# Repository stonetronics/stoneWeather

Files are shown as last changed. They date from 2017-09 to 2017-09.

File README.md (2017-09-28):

# stoneweather
Small IOT Weather station using Wifi Module WeMos D1 Mini, Pressure/Temperature Sensor HP03S, Relative Air Humidity/Temperature Sensor HTU21 LDO AMS1117

Newer version using WeMos D1 Mini, kicking out the ATmega328 to reduce complexity

Hardware Layout drawn in Eagle 8.0
coming soon!

Code for WeMos D1 Mini written in Arduino IDE (esp8266_d1mini_weather_station_v2)
-Measures temperature and air pressure using HP03s (custom .cpp and .h mixed up of "github.com/philippG777/HP03S" and "codebender.cc/sketch:42077#HP03S.ino"
-Measures temperature and relative air humidity using HTU21 (sparkfun Library)
-Displays all Data on a very simple Website to be used by a data collector (see github.com/ringo96/weatherstation)

Old Version using ATmega328 and ESP8266:

Hardware Layout drawn in Eagle 8.0
-Header for ESP8266 and GY21-HTU21 breakout boards mounted SMD
-all components SMD except for LED and XTAL

Code for ESP8266 written in Arduino IDE (esp8266displayUart)
-Reads temperature and air pressure on uart and displays it on a very simple website to be used by a data collector (see github.com/ringo96/weatherstation)

Code for ATMega328 written in Arduino IDE (HP03sUART)
-Measures temperature and air pressure with an HP03S sensor and displays it on uart

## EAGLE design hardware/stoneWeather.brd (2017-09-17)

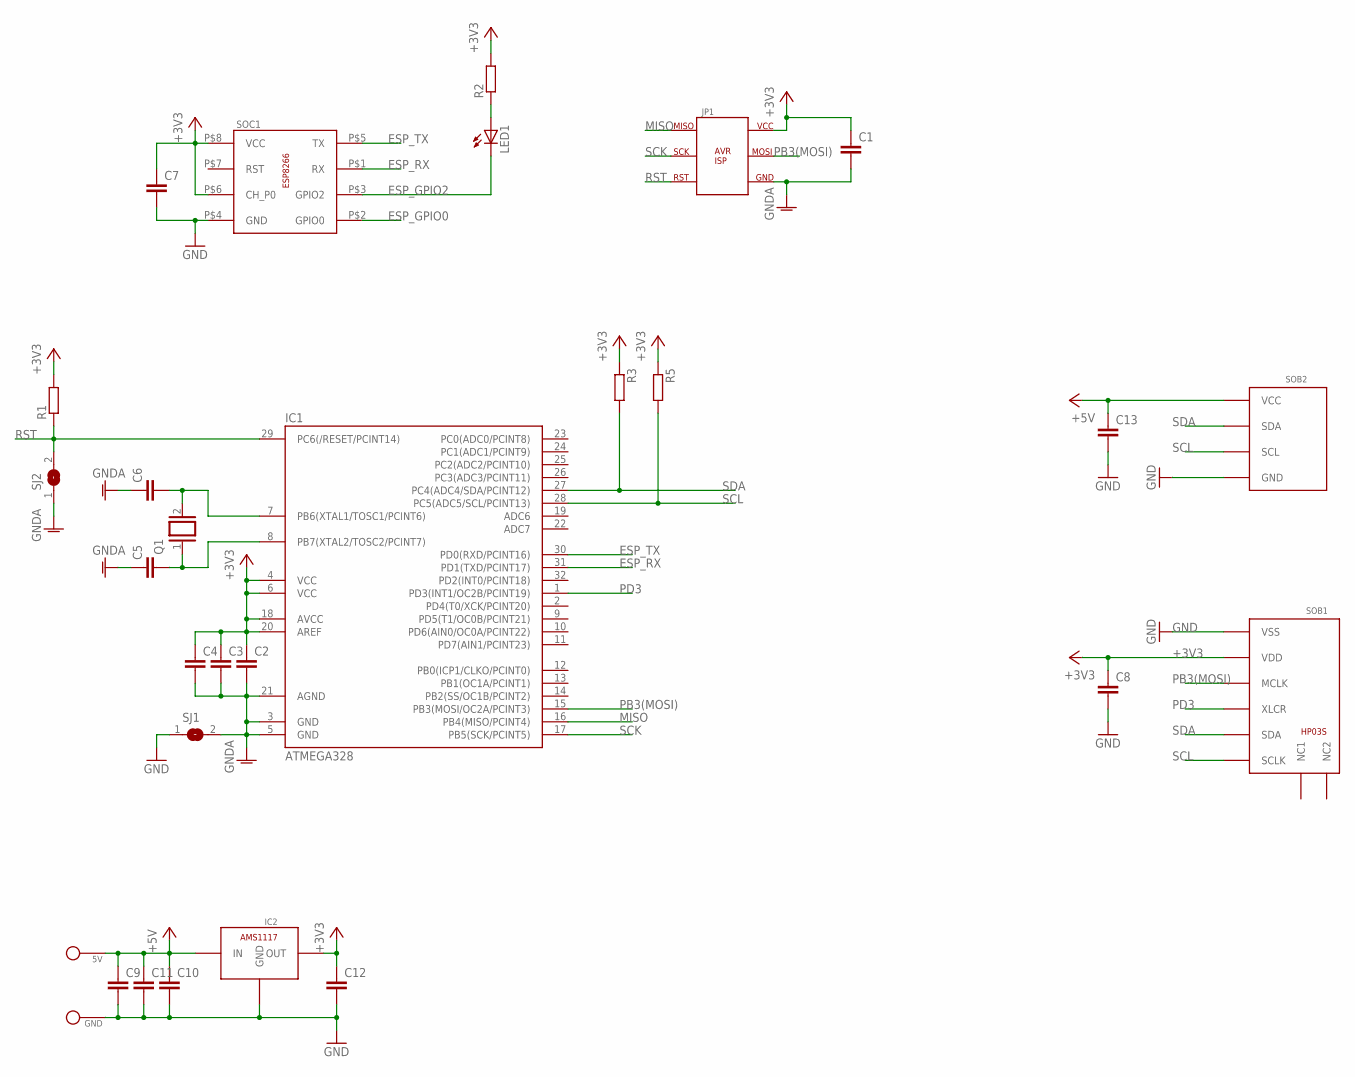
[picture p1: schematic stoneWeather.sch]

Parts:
5V: PAD_254X508
C1, C2, C3, C4, C5, C6, C7, C8, C9, C10, C11, C12, C13: C-EUC0805; C0805
GND: PAD_254X508
IC1: ATMEGA328; TQFP32-08
IC2: AMS1117
JP1: AVR_ISPSINGLESIDED_SMD; PINHEADER_254_2X3_SMD
LED1: LED3MM
Q1: XTAL/S; QS
R1, R2, R3, R5: R-EU_M0805; M0805
SJ1, SJ2: SJ
SOB1: HP03S
SOB2: GY21_HTU21; GY21-HTU21
SOC1: ESP8266PINHEADER_SMD; ESP8266

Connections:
+3V3: C1.1, C2.1, C3.1, C4.1, C7.1, C8.1, C12.1, IC1.4 (VCC), IC1.6 (VCC), IC1.18 (AVCC), IC1.20 (AREF), IC2.OUT, JP1.P$8 (VCC), R1.2, R2.2, R3.1, R5.1, SOB1.VDD, SOC1.P$6 (CH_P0), SOC1.P$8 (VCC)
+5V: 5V.P$1, C9.1, C10.1, C11.1, C13.1, IC2.IN, SOB2.P$4 (VCC)
ESP_GPIO0: SOC1.P$2 (GPIO0)
ESP_GPIO2: LED1.K (C), SOC1.P$3 (GPIO2)
ESP_RX: IC1.31 (PD1(TXD/PCINT17)), SOC1.P$1 (RX)
ESP_TX: IC1.30 (PD0(RXD/PCINT16)), SOC1.P$5 (TX)
GND: C7.2, C8.2, C9.2, C10.2, C11.2, C12.2, C13.2, GND.P$1, IC2.GND, SJ1.1, SOB1.VSS, SOB2.P$3 (GND), SOC1.P$4 (GND)
GNDA: C1.2, C2.2, C3.2, C4.2, C5.1, C6.1, IC1.3 (GND), IC1.5 (GND), IC1.21 (AGND), JP1.P$6 (GND), SJ1.2, SJ2.1
MISO: IC1.16 (PB4(MISO/PCINT4)), JP1.P$1 (MISO)
unnamed: LED1.A, R2.1
unnamed: C5.2, IC1.8 (PB7(XTAL2/TOSC2/PCINT7)), Q1.1
unnamed: C6.2, IC1.7 (PB6(XTAL1/TOSC1/PCINT6)), Q1.2
PB3(MOSI): IC1.15 (PB3(MOSI/OC2A/PCINT3)), JP1.P$7 (MOSI), SOB1.MCLK
PD3: IC1.1 (PD3(INT1/OC2B/PCINT19)), SOB1.XCLR (XLCR)
RST: IC1.29 (PC6(/RESET/PCINT14)), JP1.P$3 (RST), R1.1, SJ2.2
SCK: IC1.17 (PB5(SCK/PCINT5)), JP1.P$2 (SCK)
SCL: IC1.28 (PC5(ADC5/SCL/PCINT13)), R5.2, SOB1.SCLK, SOB2.P$2 (SCL)
SDA: IC1.27 (PC4(ADC4/SDA/PCINT12)), R3.2, SOB1.SDA, SOB2.P$1 (SDA)

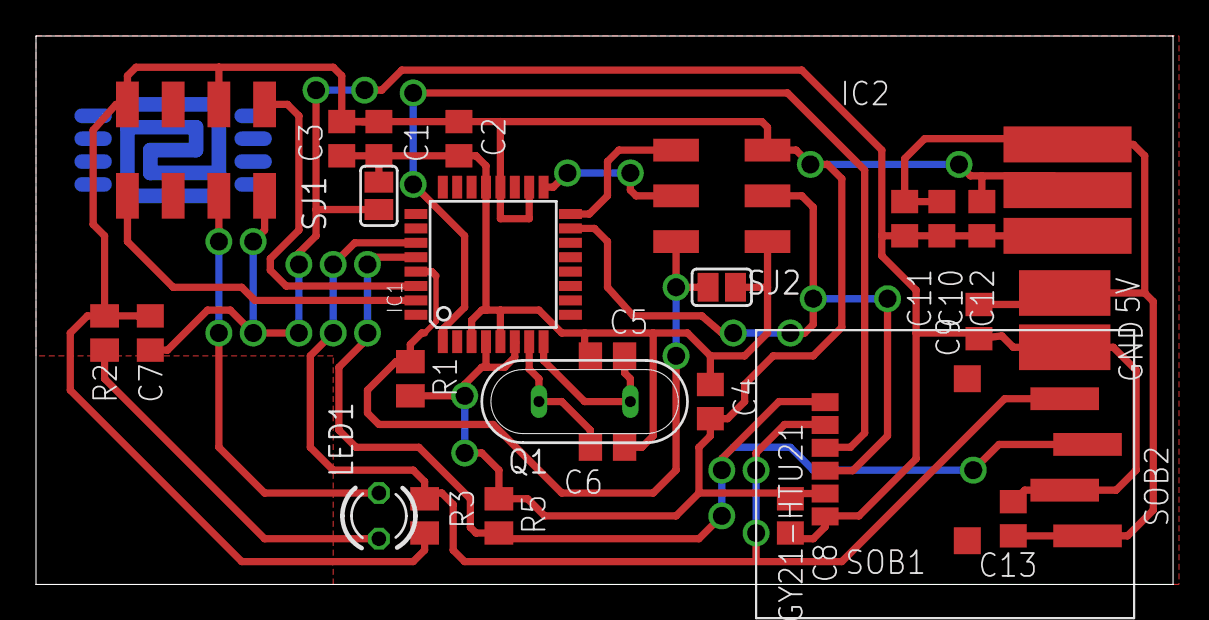
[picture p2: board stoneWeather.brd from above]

Board: 2 copper layers, 63.2 x 30.5 mm, 29 parts (0 on the bottom side), 17 nets.

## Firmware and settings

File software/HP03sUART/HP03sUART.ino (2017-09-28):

/* 
HP03S ---> Arduino Board
Vss   ---> GND
Vdd   ---> 3.3V
MCLK  ---> pin 11 Frequencytimer2_pin 32.767 khz
XCLR  ---> pin 3 pin low(EE-Mode) high(AD-Mode)
SDA   ---> SDA
SCLK  ---> SCL
*/
#include <FrequencyTimer2.h>
#include <Wire.h>

#define EEADDR 0x50
#define ADADDR 0x77
#define EESTART 0x10
#define PRESSURE 0xF0
#define TEMPERATURE 0xE8
#define MODE_AIR 0
#define MODE_TEMP 1
#define XCLR 3

unsigned char readParams[18];
int count = 0, x = 0;

float airPressure;
float temperature;

void setup() {
  pinMode(FREQUENCYTIMER2_PIN, OUTPUT);
  pinMode(XCLR, OUTPUT);
 // pinMode(A4, HIGH);
//  pinMode(A5, HIGH);
  digitalWrite(XCLR, HIGH);

  Serial.begin(115200);
  Wire.begin();
  FrequencyTimer2::setPeriod(32);
  FrequencyTimer2::enable();  

  readEE(readParams);
 // showParams();
}

void loop() { 
  delay(5000);
  calcData();
  Serial.print(temperature);
  Serial.print("\t");
  Serial.println(airPressure);
 /* if(Serial.available()>0){
    if(Serial.readString() == "t")
    {
      //Serial.println("Performing Measurement");
      calcData();
      //Serial.print("airPressure = ");
      Serial.print(airPressure);
      //Serial.print(" hpa; temperature = ");
      Serial.print("\t");
      Serial.println(temperature);
      //Serial.println(" °C");
//      showParams();
    }
  }*/
  

  
}

int readEE(unsigned char Parameter[])  {
  int a = 0; 
  digitalWrite(XCLR, LOW);
  delay(4);
  Wire.beginTransmission(EEADDR);
  Wire.write(EESTART);
  Wire.endTransmission();
  delay(5);
  Wire.requestFrom(EEADDR, 18);
  while(Wire.available())  {
    Parameter[a] = Wire.read();
    a ++;
  }  
  
  digitalWrite(XCLR, HIGH);
  return a;
}
/*
void showParams(void)  {
  int x = 0;
  count = readEE(readParams);

  for(int c = 0; c < 7; c ++)  {
    Serial.println((readParams[c + x] << 8) + readParams[c + 1 + x]);
    x = c + 1;
  }
  for(int c = 0; c < 4; c ++)  {
    Serial.println(readParams[c + 14]);
  }
}*/

 word readAD(short Mode)  {
  byte ADValue[2], d = 0;
  unsigned int AD = 0;
    
  switch(Mode)  {
  
  case MODE_AIR:
    digitalWrite(XCLR, HIGH);
    Wire.beginTransmission(ADADDR);
    Wire.write(0xFF);
    Wire.write(PRESSURE);
    Wire.endTransmission();
    delay(45);

    Wire.beginTransmission(ADADDR);
    Wire.write(0xFD);
    Wire.endTransmission();
  delay(5);
    Wire.requestFrom(ADADDR, 2);
    while(Wire.available())  {
      ADValue[d] = Wire.read(); 
      d ++;
    }
    digitalWrite(XCLR, LOW);
    break;

  case MODE_TEMP:
    digitalWrite(XCLR, HIGH);
    Wire.beginTransmission(ADADDR);
    Wire.write(0xFF);
    Wire.write(TEMPERATURE);

    Wire.endTransmission();
    delay(45);

    Wire.beginTransmission(ADADDR);
    Wire.write(0xFD);
    Wire.endTransmission();
  delay(5);
    Wire.requestFrom(ADADDR, 2);
    while(Wire.available())  {
      ADValue[d] = Wire.read(); 
      d ++;
    }
    digitalWrite(XCLR, LOW);
    break;
  }
  
  AD = (ADValue[0] << 8) | ADValue[1];
  return AD;
}

float calcData()  {
  
 float offset = 0, sens = 0, x = 0;
 float pressure = 0, temp = 0, dut = 0;
 float D1 = 0, D2 = 0, C1 = 0, C2 = 0, C3 = 0, C4 = 0, C5 = 0, C6 = 0, C7 = 0;
 float A = 0, B = 0;
 float C = 0, D = 0;
  
  readEE(readParams);
  
  C1 = (unsigned short)((readParams[0] << 8) + readParams[1]);
  C2 = (unsigned short)((readParams[2] << 8) + readParams[3]);
  C3 = (unsigned short)((readParams[4] << 8) + readParams[5]);
  C4 = (unsigned short)((readParams[6] << 8) + readParams[7]);
  C5 = (unsigned short)((readParams[8] << 8) + readParams[9]);
  C6 = (unsigned short)((readParams[10] << 8) + readParams[11]);
  C7 = (unsigned short)((readParams[12] << 8) + readParams[13]);
  
  A = (float)readParams[14];
  B = (float)readParams[15];
  C = (float)readParams[16];
  D = (float)readParams[17];
  
  D1 = readAD(MODE_AIR);
  D2 = readAD(MODE_TEMP);   
 
  
  if(D2 >= C5) {
    dut = D2 - C5 - ((D2 - C5) / 128.0) * ((D2 - C5) / 128.0) * A / pow(2,C);
  }
  else if(D2 < C5)  {
    dut = D2 - C5 - ((D2 - C5) / 128.0) * ((D2 - C5) / 128.0) * B / pow(2,C);
  }

  offset = (C2 + (C4 - 1024) * dut / 16384) * 4;
  sens = C1 + C3 * dut / 1024;
  x = sens * (D1 - 7168) / 16384 - offset;
  
  pressure = x * 10 / 32 + C7;
  airPressure = pressure / 10.0;

  temp = 250 + dut * C6 / 65536 - dut / pow(2,D);
  temperature = (temp / 10.0);


}

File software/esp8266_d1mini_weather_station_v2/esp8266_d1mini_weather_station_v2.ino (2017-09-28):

#include <ESP8266WiFi.h>
#include <Wire.h>
#include "SparkFunHTU21D.h"
#include "HP03S.h"

#define UPDATEINTERVAL_MS 2000
 
const char* ssid = "XXXXXXXXXXXXXXXXXXX";//type your ssid
const char* password = "XXXXXXXXXXXXXXXXXXX";//type your password

int millisPrev;

float hp03sTemperature;
float hp03sPressure;
float hp03sPressureAtSeaLevel;
float htu21dTemperature;
float htu21dHumidity;
 
int ledPin = 2; // GPIO2 of ESP8266
WiFiServer server(80);//Service Port

// XCLR       MCLK
//   |______    |
//          |   |
HP03S hp03s(14, 16);

HTU21D htu21d;

void connectWifi(){
  hp03s.begin();
  htu21d.begin();
  WiFi.begin(ssid, password);
   
  while (WiFi.status() != WL_CONNECTED) {
    delay(250);
    digitalWrite(ledPin, HIGH);
    delay(250);
    digitalWrite(ledPin, LOW);
  }

  // Start the server
  server.begin();
}

 
void setup() {
  millisPrev = millis();
  Serial.begin(115200);
  delay(10);
 
  pinMode(ledPin, OUTPUT);
  digitalWrite(ledPin, HIGH);
   
  connectWifi();

  //indicate successfull startup
  digitalWrite(ledPin, LOW);
 
  // Print the IP address
  Serial.print("Use this URL to connect: ");
  Serial.print("http://");
  Serial.print(WiFi.localIP());
  Serial.println("/");
}
 
void loop() {

  int millisNow = millis();

  //overflow handling for milliseconds counter  
  if(millisNow < millisPrev){
    millisPrev = millisNow;
  }

  //measurement every UPDATEINTERVAL_MS
  if(millisNow > (millisPrev + UPDATEINTERVAL_MS))
  {
    hp03s.measureAndCalcData();
    hp03sTemperature = hp03s.getTemperature();
    hp03sPressure = hp03s.getPressure();
    hp03sPressureAtSeaLevel = hp03s.getPressureAtSeaLevel(366);

    htu21dTemperature = htu21d.readTemperature();
    htu21dHumidity = htu21d.readHumidity();
  }

  //check wifi status
  if(WiFi.status() != WL_CONNECTED){
    connectWifi();
  }
  
  // Check if a client has connected
  WiFiClient client = server.available();
  if (!client) {
    return;
  }
   
  // Wait until the client sends some data
  while(!client.available()){
    delay(1);
  }
   
  // Read the first line of the request
  String request = client.readStringUntil('\r');
  client.flush();
   
 /* if (request.indexOf("/GETDATA=TRUE") != -1) {
    requestData();
  } */

   
  // Return the response
  client.println("HTTP/1.1 200 OK");
  client.println("Content-Type: text/html");
  client.println(""); //  do not forget this one
  client.println("<!DOCTYPE HTML>");
  client.println("<html>");
  client.println("<head>");
  client.println("<title>|=| STONEWEATHER |=|</title>");
  //client.println("<link rel=\"icon\" type=\"image/png\" href=\"http://*.*.*.*/stonetronicsLogo.PNG\"");
  client.println(" /></head>");
  client.println("<body>");

  client.println("<h1>|=| STONEWEATHER |=|</h1><hr>");
  client.println("<br><h2> HP03s readings: </h2>");
  client.print("Temperature: <div id = \"hp03sTemperature\">");
  client.print(hp03sTemperature);
  client.println("</div> degree C <br><br>");
  client.print("Pressure: <div id = \"hp03sPressure\">");
  client.print(hp03sPressure);
  client.println("</div> hPa <br><br>");
  client.print("Pressure at Sea Level: <div id = \"hp03sPressureAtSeaLevel\">");
  client.print(hp03sPressureAtSeaLevel);
  client.println("</div> hPa <br>");
  client.println("<br><h2> HTU21D readings: </h2>");
  client.print("Temperatur: <div id = \"htu21dTemperature\">");
  client.print(htu21dTemperature);
  client.println("</div> degree C <br><br>");
  client.print("Humidity: <div id = \"htu21dHumidity\">");
  client.print(htu21dHumidity);
  client.println("</div> % <br>");
  client.println("<hr>");
  //client.println("<img src = \"http://*.*.*.*/stonetronicsLogo.PNG\" width = \"20%\" height = \"20%\">");
  client.println("</body>");
  client.println("</html>");
}

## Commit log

2017-09-17 updated first working version of the esp8266 and the atmega328 firmware
    [stoneWeather.brd, stoneWeather.sch]
2017-09-17 Added GY21-HTU21 breakout board header to the board Updated README.md
    [stoneWeather.brd, stoneWeather.sch]
